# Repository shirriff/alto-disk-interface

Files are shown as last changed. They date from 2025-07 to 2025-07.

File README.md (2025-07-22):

# A Diablo disk emulator for use with a Xerox Alto

Note: This is still under development and is not working yet

The concept is a small box that you can plug into the Alto's disk interface, replacing the Diablo disk. The box will emulate the disk drive,
using a disk image from a SD card.

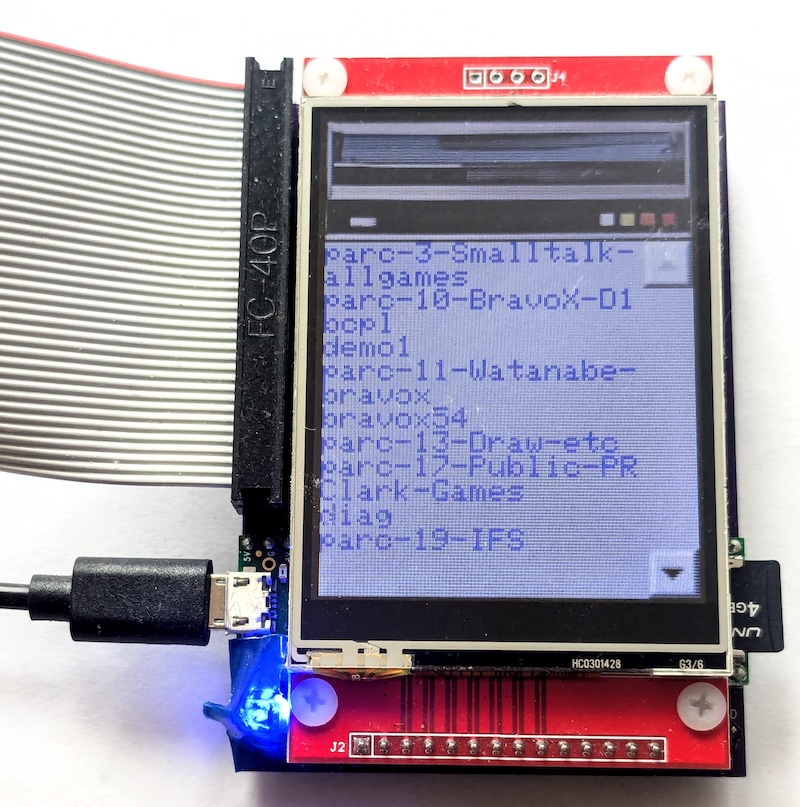
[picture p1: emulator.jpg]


The hardware design is in the interface directory. It is based on a Teensy 4.1 microcontroller and uses a LCD touch screen as the user interface.

The driver software is in the TestApp directory.

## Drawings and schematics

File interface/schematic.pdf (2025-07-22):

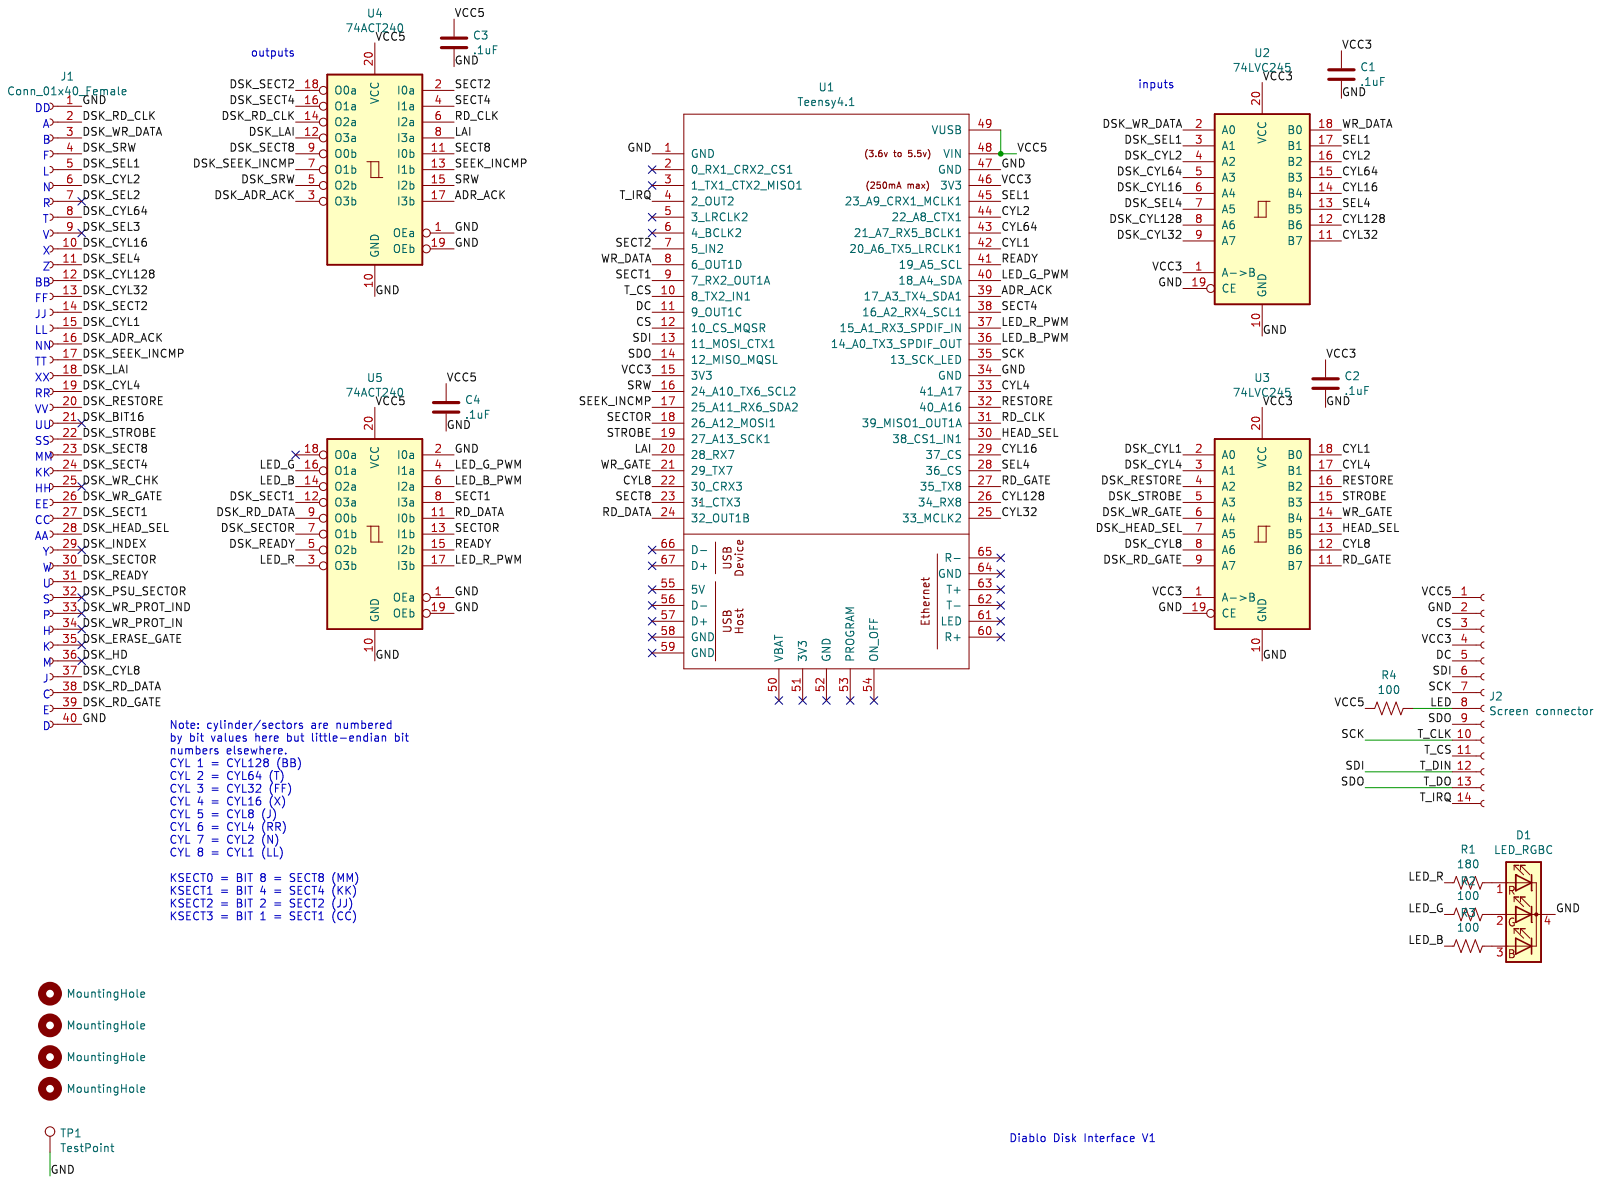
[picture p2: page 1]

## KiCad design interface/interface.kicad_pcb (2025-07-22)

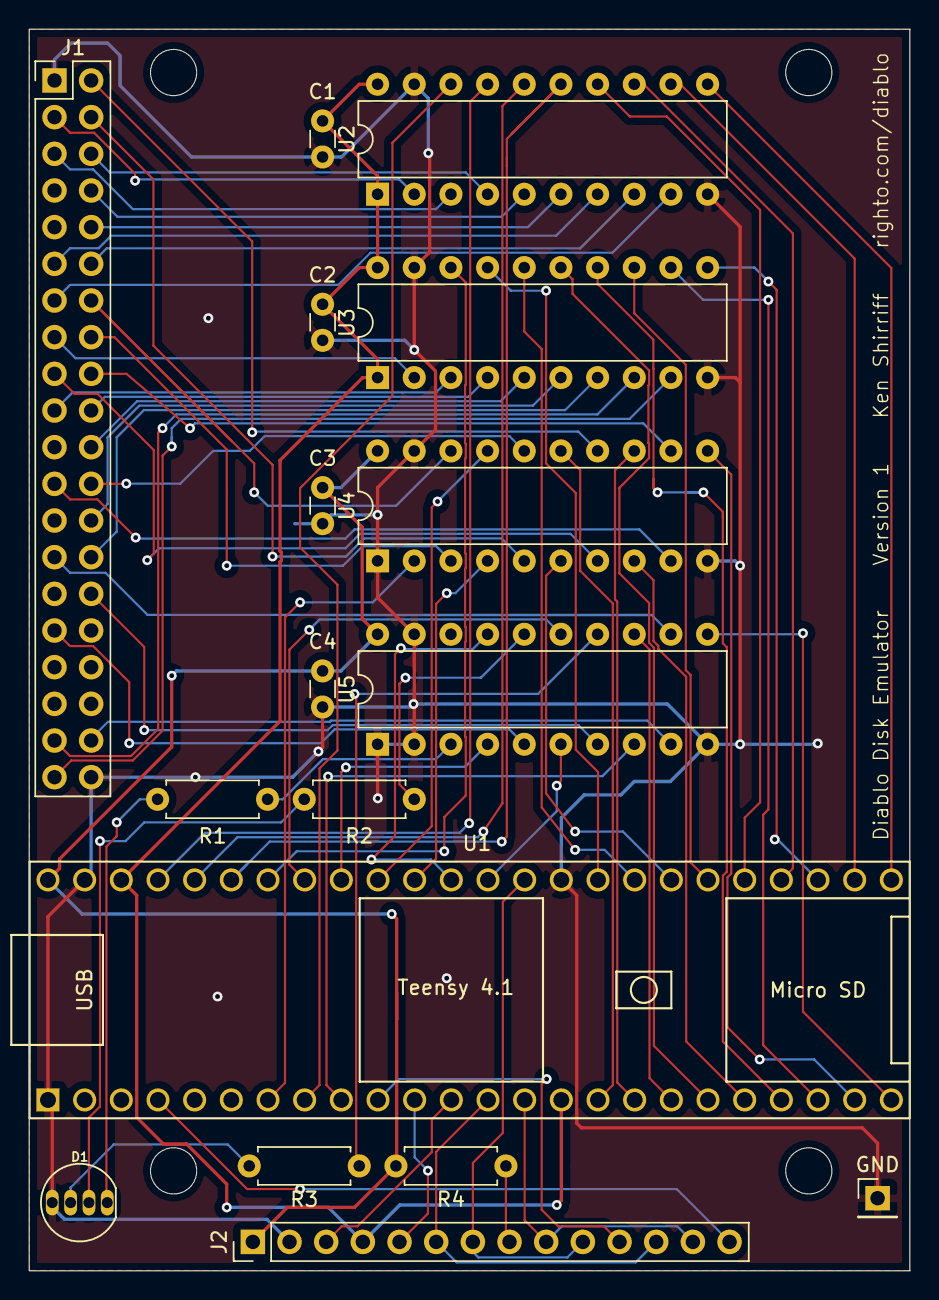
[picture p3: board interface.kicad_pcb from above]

Board: 2 copper layers, 61.0 x 86.0 mm, 21 parts (0 on the bottom side), 76 nets.

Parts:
C1, C2, C3, C4: .1uF; C_Disc_D3.0mm_W1.6mm_P2.50mm
D1: LED_RGBC; LED-RGB-THRU
GND: TestPoint; Pin_Header_Straight_1x01_Pitch2.54mm
H1, H2, H3, H4: MountingHole; MountingHole_M3
J1: Conn_01x40_Female; connector-2x20
J2: Screen connector; Pin_Header_Straight_1x14_Pitch2.54mm
R1: 180; R_Axial_DIN0207_L6.3mm_D2.5mm_P7.62mm_Horizontal
R2, R3, R4: 100; R_Axial_DIN0207_L6.3mm_D2.5mm_P7.62mm_Horizontal
U1: Teensy4.1; Teensy41_simple
U2, U3: 74LVC245; DIP-20_W7.62mm
U4, U5: 74ACT240; DIP-20_W7.62mm

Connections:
/ADR_ACK: U1.39, U4.17
/CS: J2.3, U1.12
/CYL1: U1.42, U3.18
/CYL2: U1.44, U2.16
/CYL4: U1.33, U3.17
/CYL8: U1.22, U3.12
/CYL16: U1.29, U2.14
/CYL32: U1.25, U2.11
/CYL64: U1.43, U2.15
/CYL128: U1.26, U2.12
/DC: J2.5, U1.11
/DSK_ADR_ACK: J1.16, U4.3
/DSK_CYL1: J1.15, U3.2
/DSK_CYL2: J1.6, U2.4
/DSK_CYL4: J1.19, U3.3
/DSK_CYL8: J1.37, U3.8
/DSK_CYL16: J1.10, U2.6
/DSK_CYL32: J1.13, U2.9
/DSK_CYL64: J1.8, U2.5
/DSK_CYL128: J1.12, U2.8
/DSK_HEAD_SEL: J1.28, U3.7
/DSK_LAI: J1.18, U4.12
/DSK_RD_CLK: J1.2, U4.14
/DSK_RD_DATA: J1.38, U5.9
/DSK_RD_GATE: J1.39, U3.9
/DSK_READY: J1.31, U5.5
/DSK_RESTORE: J1.20, U3.4
/DSK_SECT1: J1.27, U5.12
/DSK_SECT2: J1.14, U4.18
/DSK_SECT4: J1.24, U4.16
/DSK_SECT8: J1.23, U4.9
/DSK_SECTOR: J1.30, U5.7
/DSK_SEEK_INCMP: J1.17, U4.7
/DSK_SEL1: J1.5, U2.3
/DSK_SEL4: J1.11, U2.7
/DSK_SRW: J1.4, U4.5
/DSK_STROBE: J1.22, U3.5
/DSK_WR_DATA: J1.3, U2.2
/DSK_WR_GATE: J1.26, U3.6
/GND: C1.2, C2.2, C3.2, C4.2, D1.4, GND.1, J1.1, J1.40, J2.2, U1.1, U1.34, U1.47, U2.10, U2.19, U3.10, U3.19, U4.1, U4.10, U4.19, U5.1, U5.2, U5.10, U5.19
/HEAD_SEL: U1.30, U3.13
/LAI: U1.20, U4.8
/LED: J2.8, R4.1
/LED_B: R3.2, U5.14
/LED_B_PWM: U1.36, U5.6
/LED_G: R2.2, U5.16
/LED_G_PWM: U1.40, U5.4
/LED_R: R1.2, U5.3
/LED_R_PWM: U1.37, U5.17
/RD_CLK: U1.31, U4.6
/RD_DATA: U1.24, U5.11
/RD_GATE: U1.27, U3.11
/READY: U1.41, U5.15
/RESTORE: U1.32, U3.16
/SCK: J2.7, J2.10, U1.35
/SDI: J2.6, J2.12, U1.13
/SDO: J2.9, J2.13, U1.14
/SECT1: U1.9, U5.8
/SECT2: U1.7, U4.2
/SECT4: U1.38, U4.4
/SECT8: U1.23, U4.11
/SECTOR: U1.18, U5.13
/SEEK_INCMP: U1.17, U4.13
/SEL1: U1.45, U2.17
/SEL4: U1.28, U2.13
/SRW: U1.16, U4.15
/STROBE: U1.19, U3.15
/T_CS: J2.11, U1.10
/T_IRQ: J2.14, U1.4
/VCC3: C1.1, C2.1, J2.4, U1.15, U1.46, U2.1, U2.20, U3.1, U3.20
/VCC5: C3.1, C4.1, J2.1, R4.2, U1.48, U4.20, U5.20
/WR_DATA: U1.8, U2.18
/WR_GATE: U1.21, U3.14
unnamed: D1.1, R1.1
unnamed: D1.2, R2.1
unnamed: D1.3, R3.1

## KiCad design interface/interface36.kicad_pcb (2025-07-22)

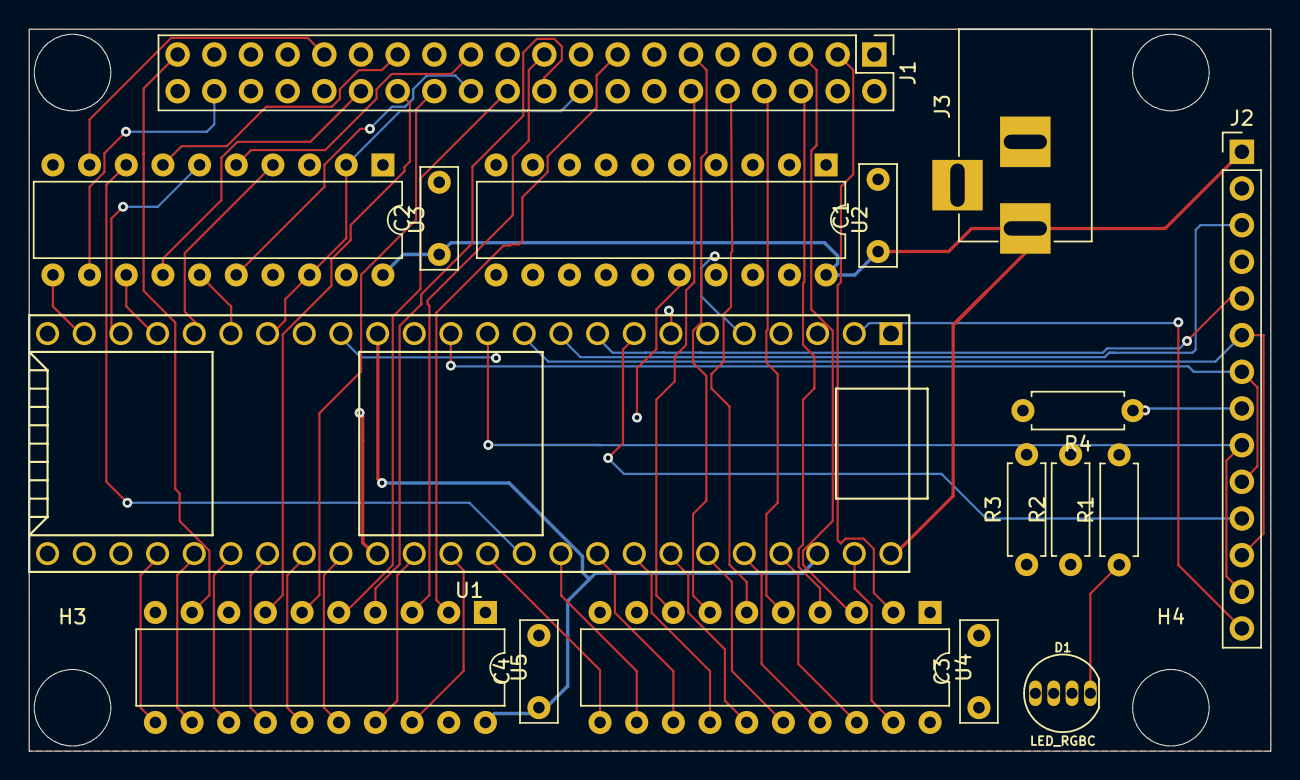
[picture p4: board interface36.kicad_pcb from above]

Board: 2 copper layers, 86.0 x 50.0 mm, 21 parts (0 on the bottom side), 75 nets.

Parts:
C1, C2, C3, C4: .1uF; C_Rect_L7.0mm_W2.5mm_P5.00mm
D1: LED_RGBC; LED-RGB-THRU
H1, H2, H3, H4: MountingHole; MountingHole_5.3mm_M5
J1: Conn_01x40_Female; Pin_Header_Straight_2x20_Pitch2.54mm
J2: Conn_01x14_Female; Pin_Header_Straight_1x14_Pitch2.54mm
J3: Jack-DC; BARREL_JACK
R1: 180; R_Axial_DIN0207_L6.3mm_D2.5mm_P7.62mm_Horizontal
R2, R3, R4: 100; R_Axial_DIN0207_L6.3mm_D2.5mm_P7.62mm_Horizontal
U1: Teensy3.6; Teensy_36_simple
U2, U3: 74ACT240; DIP-20_W7.62mm
U4, U5: 74LVC245; DIP-20_W7.62mm

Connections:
/ADR_ACK: U1.16, U2.8
/CS: J2.3, U1.10
/CYL1: U1.39, U4.12
/CYL2: U1.42, U4.15
/CYL3: U1.37, U4.11
/CYL4: U1.41, U4.14
/CYL5: U1.29, U5.12
/CYL6: U1.35, U5.17
/CYL7: U1.43, U4.16
/CYL8: U1.36, U5.18
/DC: J2.5, U1.9
/DSK_ADR_ACK: J1.16, U2.12
/DSK_CYL1: J1.12, U4.8
/DSK_CYL2: J1.8, U4.5
/DSK_CYL3: J1.13, U4.9
/DSK_CYL4: J1.10, U4.6
/DSK_CYL5: J1.37, U5.8
/DSK_CYL6: J1.19, U5.3
/DSK_CYL7: J1.6, U4.4
/DSK_CYL8: J1.15, U5.2
/DSK_HEAD_SEL: J1.28, U5.7
/DSK_KSECT0: J1.23, U3.5
/DSK_KSECT1: J1.24, U3.16
/DSK_KSECT2: J1.14, U2.16
/DSK_KSECT3: J1.27, U3.7
/DSK_LAI: J1.18, U1.18, U3.2, U3.18
/DSK_RD_CLK: J1.2, U2.18
/DSK_RD_DATA: J1.38, U3.12
/DSK_RD_GATE: J1.39, U5.9
/DSK_READY: J1.31, U3.9
/DSK_RESTORE: J1.20, U5.4
/DSK_SECTOR: J1.30, U3.14
/DSK_SEEK_INCMP: J1.17, U2.9
/DSK_SEL1: J1.5, U4.3
/DSK_SEL4: J1.11, U4.7
/DSK_SRW: J1.4, U2.3
/DSK_STROBE: J1.22, U5.5
/DSK_WR_DATA: J1.3, U4.2
/DSK_WR_GATE: J1.26, U5.6
/GND: C1.2, C2.2, C3.2, C4.2, D1.4, J1.1, J1.40, J2.2, J3.2, U1.1, U1.34, U1.47, U2.1, U2.10, U2.19, U3.1, U3.10, U3.17, U3.19, U4.10, U4.19, U5.10, U5.19
/HEAD_SEL: U1.30, U5.13
/KSECT0: U1.19, U3.15
/KSECT1: U1.20, U3.4
/KSECT2: U1.7, U2.4
/KSECT3: U1.21, U3.13
/LED: J2.8, R4.1
/LED_B: R3.2, U2.7
/LED_B_PWM: U1.5, U2.13
/LED_G: R2.2, U2.14
/LED_G_PWM: U1.4, U2.6
/LED_R: R1.2, U2.5
/LED_R_PWM: U1.3, U2.15
/RD_CLK: U1.14, U2.2
/RD_DATA: U1.38, U3.8
/RD_GATE: U1.28, U5.11
/READY: U1.23, U3.11
/RESTORE: U1.33, U5.16
/SCK: J2.7, J2.10, U1.13
/SDI: J2.6, J2.12, U1.11
/SDO: J2.9, J2.13, U1.12
/SECTOR: U1.22, U3.6
/SEEK_INCMP: U1.17, U2.11
/SEL1: U1.44, U4.17
/SEL4: U1.40, U4.13
/SRW: U1.6, U2.17
/STROBE: U1.32, U5.15
/T_CS: J2.11, U1.8
/T_IRQ: J2.14, U1.2
/VCC3: C3.1, C4.1, J2.4, U1.15, U1.46, U4.1, U4.20, U5.1, U5.20
/VCC5: C1.1, C2.1, J2.1, J3.1, R4.2, U1.48, U2.20, U3.20
/WR_DATA: U1.45, U4.18
/WR_GATE: U1.31, U5.14
unnamed: D1.1, R1.1
unnamed: D1.2, R2.1
unnamed: D1.3, R3.1

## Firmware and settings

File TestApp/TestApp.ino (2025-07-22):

/**
 * Main program.
 * Dependencies:
 * Adafruit_GFX
 * Adafruit_ILI9341
 */
#include "gui.h"
#include "board.h"
#include "sd.h"

// Main entry point
void setup(void) {
  Serial.println("setupBoard...");
  setupBoard();
  Serial.println("setupGUI...");
  setupGui();
  setupSD();

  fetchDirectory();
  displaySelector();
}


void loop()
{
  loopBoard();
}

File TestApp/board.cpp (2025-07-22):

#include "Arduino.h"
#include "board.h"
#include "gui.h"
#include "sd.h"

/*
   Handle the disk I/O.

   State signals:
   IDLE -> LOADED when a disk is loaded
   On Strobe: read track address / restore, activate address acknowledge (or LAI on error)
   Restore + Strobe: move to track 0, Address Ack
   Head select: held for duration of read/write
   SRW
   Sector mark: 5 microsecond pulse every 3.33 ms, output sector number
   Write gate: start processing data
   Read gate: start feeding data. Need to handle switching to write gate in middle of sector.
   Outputs:
   Ready: disk loaded, ready to go
   SRW: Ready and not in the middle of a seek; can perform operation.
   Addr Ack: seek has been accepted and started. 2.5 to 7.5 usec wide pulse. Happens between 22.5 and 47.5 usec after Strobe. Alternative is LAI for bad track
   Seek incomplete: a fault during the seek. Held until Restore is issued.
   Sector marks: 5 usec pulse on each sector slot
   Sector address: updated on leading edge of each sector mark.

*/

#define STATE_UNLOADED 1
#define STATE_LOADED 2

volatile int state = STATE_UNLOADED;
boolean disconnected = false;  // Running in disconnected mode



// Sector variables
IntervalTimer sectorTimer;
volatile int sectorCount;
volatile unsigned long sectorStartMicros;  // Time at sector start


// Setup board stuff
void setupBoard() {
  pinMode(SECTOR, OUTPUT);
  pinMode(RD_CLK, OUTPUT);
  pinMode(RD_DATA, OUTPUT);
  pinMode(LAI, OUTPUT);
  pinMode(SRW, OUTPUT);
  pinMode(SEEK_INCMP, OUTPUT);
  pinMode(ADR_ACK, OUTPUT);
  pinMode(READY, OUTPUT);
  pinMode(SECT1, OUTPUT);
  pinMode(SECT2, OUTPUT);
  pinMode(SECT4, OUTPUT);
  pinMode(SECT8, OUTPUT);

  digitalWrite(SECTOR, OFF);
  digitalWrite(RD_CLK, OFF);
  digitalWrite(RD_DATA, OFF);
  digitalWrite(LAI, OFF);
  digitalWrite(SRW, OFF);
  digitalWrite(SEEK_INCMP, OFF);
  digitalWrite(ADR_ACK, OFF);
  digitalWrite(READY, OFF);
  digitalWrite(SECT1, OFF);
  digitalWrite(SECT2, OFF);
  digitalWrite(SECT4, OFF);
  digitalWrite(SECT8, OFF);

  // Inputs are active-low. Outputs are also active-low, but the driver is an inverter.
  pinMode(WR_DATA, INPUT);
  pinMode(SEL1, INPUT);
  pinMode(SEL4, INPUT);
  pinMode(CYL1, INPUT);
  pinMode(CYL2, INPUT);
  pinMode(CYL4, INPUT);
  pinMode(CYL8, INPUT);
  pinMode(CYL16, INPUT);
  pinMode(CYL32, INPUT);
  pinMode(CYL64, INPUT);
  pinMode(CYL128, INPUT);
  pinMode(RESTORE, INPUT);
  pinMode(STROBE, INPUT);
  pinMode(WR_GATE, INPUT);
  pinMode(RD_GATE, INPUT);
  pinMode(HEAD_SEL, INPUT);

  // flash green, just to show board is active
  analogWrite(LED_G, 256);  // Inverted, so 256 is off
  analogWrite(LED_R, 256);
  analogWrite(LED_B, 256);
  delay(250);
  analogWrite(LED_G, 128);
  delay(250);
  analogWrite(LED_G, 256);
  led(RED);
  delay(1000);
  led(GREEN);
  delay(1000);
  led(BLUE);
  delay(1000);
  Serial.println("setupBoard done");
  if (digitalRead(RD_GATE) == 0 || digitalRead(WR_GATE) == 0 || digitalRead(STROBE) == 0) {
    Serial.println("Disconnected mode");
    disconnected = true;
  }
}

// Print input vector if it changes.
// Inputs are active-low.
int lastInput = -1;
void inTest() {
  int n = 0;
  if (digitalReadFast(WR_DATA)) n |= 1;
  if (digitalReadFast(SEL1)) n |= 2;
  if (digitalReadFast(SEL4)) n |= 4;
  if (digitalReadFast(CYL1)) n |= 8;
  if (digitalReadFast(CYL2)) n |= 16;
  if (digitalReadFast(CYL4)) n |= 32;
  if (digitalReadFast(CYL8)) n |= 64;
  if (digitalReadFast(CYL16)) n |= 128;
  if (digitalReadFast(CYL32)) n |= 256;
  if (digitalReadFast(CYL64)) n |= 512;
  if (digitalReadFast(CYL128)) n |= 1024;
  if (digitalReadFast(RESTORE)) n |= 2048;
  if (digitalReadFast(STROBE)) n |= 4096;
  if (digitalReadFast(WR_GATE)) n |= 8192;
  if (digitalReadFast(RD_GATE)) n |= 16384;
  if (digitalReadFast(HEAD_SEL)) n |= 32768;

  if (n != lastInput) {
    Serial.print("Inputs: ");
    Serial.print(0x7fff ^ n, HEX);
    if (!(n & 1)) {
      Serial.print(" WR_DATA");
    }
    if (!(n & 2)) {
      Serial.print(" SEL1");
    }
    if (!(n & 4)) {
      Serial.print(" SEL4");
    }
    int cyl = (~(n >> 8)) & 0xff;

    Serial.printf(" CYL %d", cyl);

    if (!(n & 2048)) {
      Serial.print(" RESTORE");
    }

    if (!(n & 4096)) {
      Serial.print(" STROBE");
    }

    if (!(n & 8192)) {
      Serial.print(" WR_GATE");
    }

    if (!(n & 16384)) {
      Serial.print(" RD_GATE");
    }

    if (!(n & 32768)) {
      Serial.print(" HEAD_SEL");
    }
    Serial.println("");
    lastInput = n;
  }
}

int debug = 0;

int blink = 1;
unsigned long lastSectorStartMicros = 0;
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
